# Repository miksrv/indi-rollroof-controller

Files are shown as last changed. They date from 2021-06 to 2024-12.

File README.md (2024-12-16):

# Observatory Roof Controller

 


A fork of the original [INDI Aldiroof](https://github.com/dokeeffe/indi-aldiroof) project by Derek O'Keeffe, designed for simplified roll-off roof mechanisms requiring only two signals: **OPEN** and **CLOSE**.

This project includes an [INDI](http://indilib.org/) driver and Arduino firmware to manage a roll-off roof for astronomical observatories.

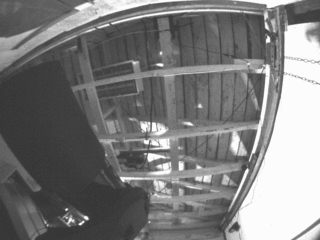
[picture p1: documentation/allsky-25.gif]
Observatory in Action


## Key Features

- **Efficient Roof Operation**: Control a motor-driven sliding gate reducer with just two signals.
- **Hardware Safety**: Includes limit switches for roof position and reed switches for telescope parking.
- **Simple Electronics**: Two 30A relays connected to an Arduino handle all roof movements.
- **Seamless Communication**: Uses the Firmata protocol for interaction between the Arduino and the INDI driver.

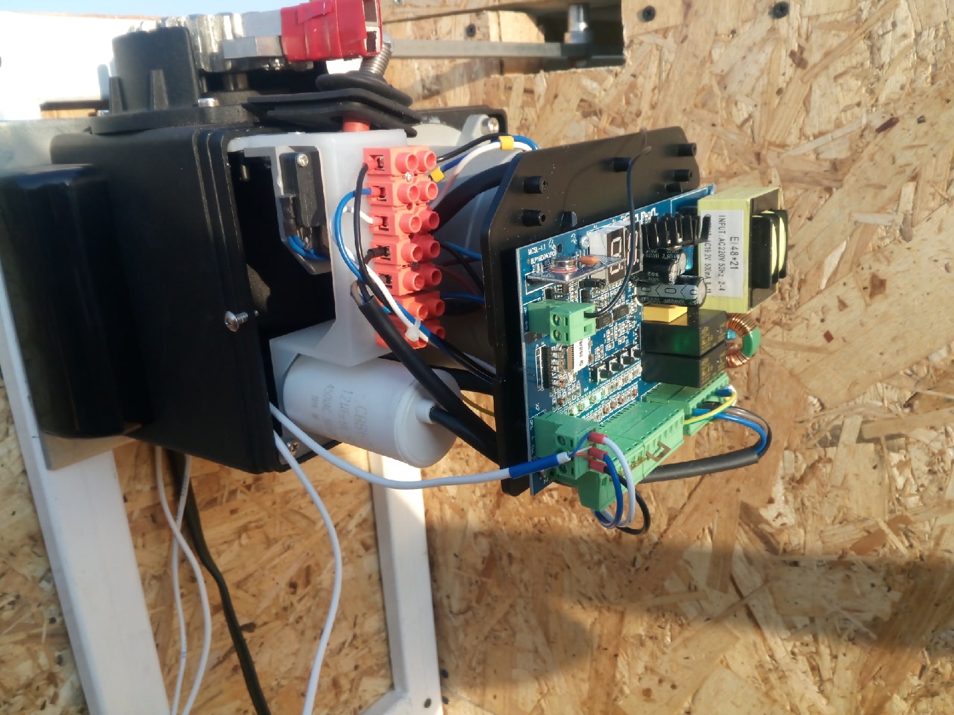
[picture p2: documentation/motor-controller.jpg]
Motor Controller Hardware


## Hardware Requirements

### Components
- **Microcontroller**: Arduino UNO (or compatible board).
- **Relays**: Two 30A relay modules.
- **Sensors**: Limit switches and reed switches for positional feedback.
- **Server**: A Linux-based machine running the INDI server.
- *(Optional)* A custom 3D-printed case for the hardware.

## Software Setup

### 1. Flashing the Arduino Firmware
1. Open the [Arduino IDE](https://www.arduino.cc/en/software).
2. Connect your Arduino board to your computer.
3. Navigate to the `arduino-firmware/RoofController` directory.
4. Open `RoofController.ino` and upload the firmware.

### 2. Building and Installing the INDI Driver

1. **Install Required Dependencies**  
   Make sure your system is up to date and install the necessary libraries:
   ```bash
   sudo apt-get update
   sudo apt-get install -y cmake libindi-dev libnova-dev
   ```

2. **Clone the Repository**  
   Clone this project to your machine:
   ```bash
   git clone <repository-url>
   cd <repository-directory>
   ```

3. **Build and Install the Driver**  
   Run the provided script:
   ```bash
   chmod +x ./indi-rollroof/install.sh
   ./indi-rollroof/install.sh
   ```
   This script will:
   - Create a `build` directory.
   - Configure the driver using `cmake`.
   - Compile and install the driver via `make install`.

### 3. Configuring the INDI Web Manager
To integrate the driver with the INDI Web Manager:
1. Open `/usr/share/indi/drivers.xml` for editing:
   ```bash
   sudo nano /usr/share/indi/drivers.xml
   ```
2. Add this configuration under the `<Domes>` section:
   ```xml
   <device label="Roll Roof" manufacturer="miksoft">
     <driver name="Roll Roof">indi_rollroof</driver>
     <version>1.0</version>
   </device>
   ```
3. Save and restart the INDI Web Manager.

### 4. Wiring and Hardware Setup
- Wire the Arduino with relays, sensors, and motor as outlined in the [wiring diagram](./documentation/arduino-controller.jpg).
- Ensure that:
  - Limit switches are positioned to detect the fully open and closed states.
  - Reed switches confirm the telescope’s parked position before closing the roof.

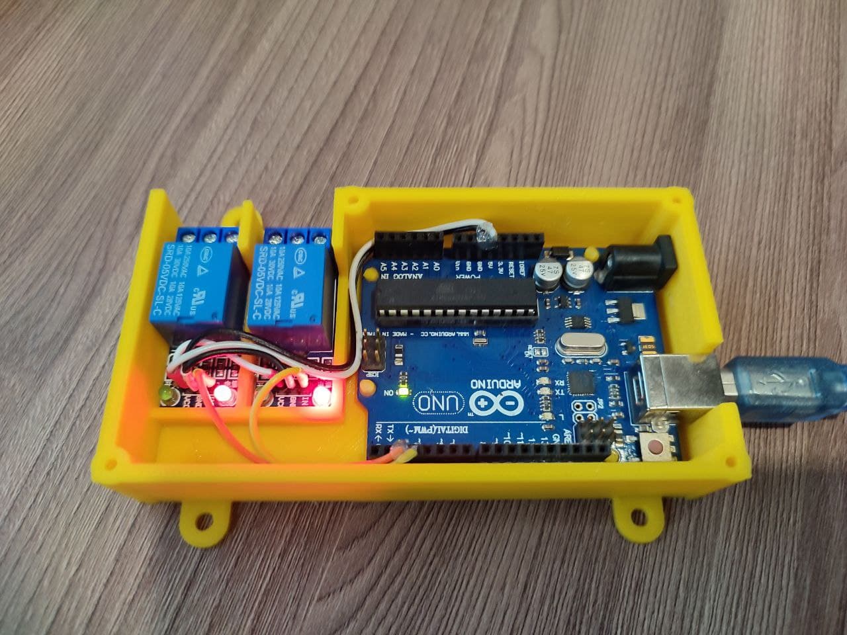
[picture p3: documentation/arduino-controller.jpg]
Arduino Wiring Diagram


## Contributing

Contributions are welcome! If you encounter bugs or have suggestions for improvements:
1. Fork the repository.
2. Create a feature branch.
3. Submit a pull request.

## Acknowledgments

This project is based on the work of [Derek O'Keeffe](https://github.com/dokeeffe/indi-aldiroof) and leverages the powerful [INDI Library](http://indilib.org/).  
Special thanks to the open-source community for enabling projects like this.

### License
This project is licensed under the [MIT License](./LICENSE).

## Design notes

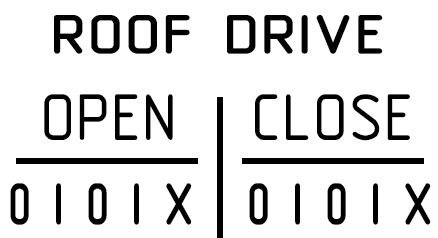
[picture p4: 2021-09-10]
models/label-1.png

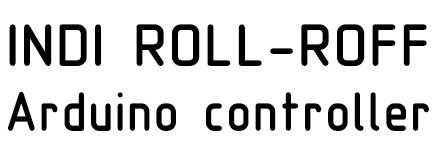
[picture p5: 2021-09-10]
models/label-3.png

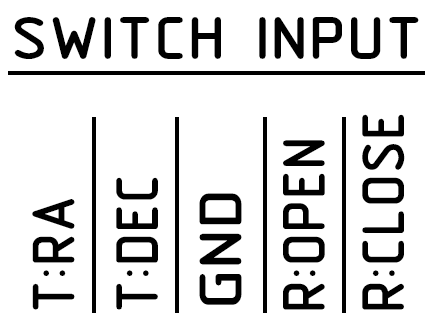
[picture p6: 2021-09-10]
models/label-2.png

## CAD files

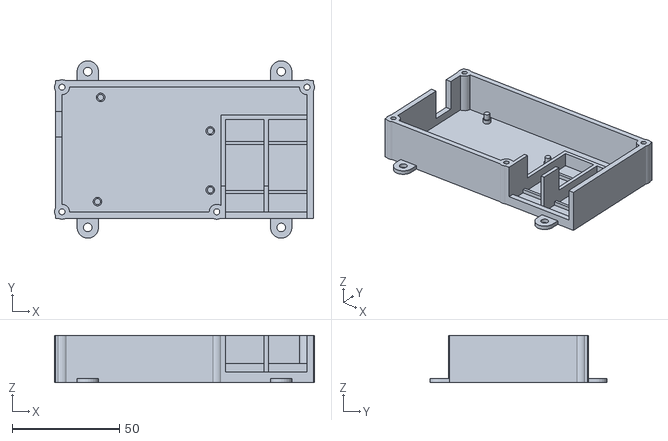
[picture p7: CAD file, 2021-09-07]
models/arduino-2relay-case.stl
121.0 x 82.5 x 22.0

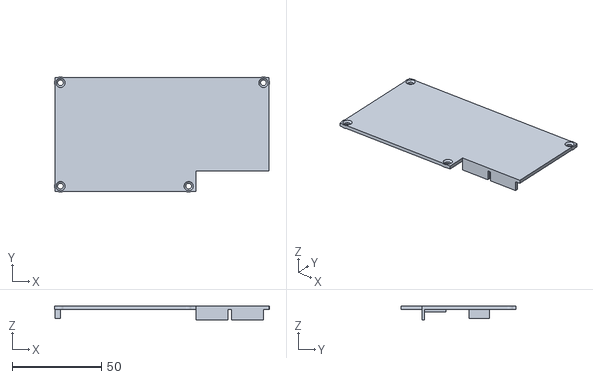
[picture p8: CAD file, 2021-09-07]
models/arduino-2relay-cover.stl
120.8 x 64.7 x 7.80

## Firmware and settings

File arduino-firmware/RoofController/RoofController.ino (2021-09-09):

/*******************************************************************************
 * OBSERVATORY ROLL-OFF-ROOF FIRMWARE
 * 
 * Firmware for a Arduino controller Roll-Off-Roof observatory. A simple 
 * state-machine based on StandardFirmata, comminicates with indiserver indi_rollroof driver.
 * NOTE: Firmata does not function well over USB3. Always use a USB2 port!
 * 
 * Sept 2015 Derek OKeeffe
 * Sept 2019 Mikhail Topchilo (miksoft.pro)
*******************************************************************************/
#include <Wire.h>
#include <Firmata.h>

/**
 * ======= CONFIGURATION =======
 */
// If the variable is not commented out, debug mode is activated, messages are sent to the serial port
// #define DEBUG

const int pinRelayOpen        = 2; // RELAY: Open roof
const int pinRelayClose       = 3; // RELAY: Close roof
const int pinLimitSwitchClose = 4; // SWITCH: Closed roof limit switch 
const int pinLimitSwitchOpen  = 5; // SWITCH: Opened roof limit switch 
const int parkTelescopeDEC    = 6; // SWITCH: Telescope parking position on the axis DEC
const int parkTelescopeRA     = 7; // SWITCH: Telescope parking position on the axis RA
const int ledPin              = 13; // INDICATOR: Pin for connecting a visual indicator of the roof position (for DEBUG)

long ledToggleTime = 0;
bool ledState;
int openState, closeState, parkStateRa, parkStateDec;

/**
 * ======= SETUP =======
 */
void setup()
{
  Firmata.setFirmwareVersion(FIRMATA_MAJOR_VERSION, FIRMATA_MINOR_VERSION);
  Firmata.attach(STRING_DATA, stringCallback);
  Firmata.begin(57600);
  pinMode(pinRelayOpen, OUTPUT);
  pinMode(pinRelayClose, OUTPUT);
  
  pinMode(pinLimitSwitchOpen, INPUT_PULLUP); // INPUT
  pinMode(pinLimitSwitchClose, INPUT_PULLUP); // INPUT

  pinMode(parkTelescopeRA, INPUT_PULLUP);
  pinMode(parkTelescopeDEC, INPUT_PULLUP);
  
  pinMode(ledPin, OUTPUT);

  // By default, the relays should be turned off, so we give them a high signal 
  digitalWrite(pinRelayOpen, HIGH);
  digitalWrite(pinRelayClose, HIGH);
}

/**
 * ======= LOOP =======
 */
void loop()
{
  while (Firmata.available()) {
    Firmata.processInput();
  }

  #ifdef DEBUG
    debugLEDs();
  #endif
}

/**
 * ======= FIRMATA HANDLER =======
 */
void stringCallback(char *myString) {
  openState  = digitalRead(pinLimitSwitchOpen);
  closeState = digitalRead(pinLimitSwitchClose);
  parkStateRa  = digitalRead(parkTelescopeRA);
  parkStateDec = digitalRead(parkTelescopeDEC);
  
  String commandString = String(myString);

  // CMD: Open roof
  if (commandString.equals("OPEN") && (parkStateRa == LOW && parkStateDec == LOW))
    actionRoofOpen();

  // CMD: Close roof
  else if (commandString.equals("CLOSE") && (parkStateRa == LOW && parkStateDec == LOW))
    actionRoofClose();

  // CMD: Abort command
  else if (commandString.equals("ABORT")) {
    return ;
  }

  // CMD: Query status
  /**
   * 10 - Roof closed, telescope parked
   * 20 - Roof open, telescope parked
   *
   * 11 - Roof closed, no parking (DEC, RA)
   * 12 - Roof closed, no parking (DEC)
   * 13 - Roof closed, no parking (RA)
   *
   * 21 - Roof open, no parking (DEC, RA)
   * 22 - Roof open, no parking (DEC)
   * 23 - Roof open, no parking (RA)
   */
  else if (commandString.equals("QUERY")) {
    int stateRoof;
    int statePark;

    if (openState == LOW && closeState == HIGH)
      stateRoof = 10; // Open roof
    
    else if (openState == HIGH && closeState == LOW)
      stateRoof = 20; // Close roof

    else
      stateRoof = 30; // Unknow


    if (parkStateDec == LOW && parkStateRa == LOW)
      statePark = 0; // PARK
      
    else if (parkStateDec == HIGH && parkStateRa == HIGH)
      statePark = 1; // NO park DEC, RA 

    else if (parkStateDec == HIGH && parkStateRa == LOW)
      statePark = 2; // NO park DEC

    else if (parkStateDec == LOW && parkStateRa == HIGH)
      statePark = 3; // NO park RA

      char cstr[8];

    return Firmata.sendString( itoa(stateRoof + statePark, cstr, 10) );
  }
}

/**
 * Close roof
 */
void actionRoofClose() {
  unsigned long activateTime = millis();

  digitalWrite(pinRelayOpen, LOW);
  while((millis() - activateTime) < 800) {}
  digitalWrite(pinRelayOpen, HIGH);
}

/**
 * Open roof
 */
void actionRoofOpen() {
  unsigned long activateTime = millis();
  
  digitalWrite(pinRelayClose, LOW);
  while((millis() - activateTime) < 800) {}
  digitalWrite(pinRelayClose, HIGH);
}

/** 
 * LED is used to provide visual clues to the state of the roof controller.
 * Really not necessary, but handy for debugging wiring and mechanical problem.
 */
void debugLEDs() {
  openState  = digitalRead(pinLimitSwitchOpen);
  closeState = digitalRead(pinLimitSwitchClose);
  
  // Opened roof
  if (closeState == HIGH && openState == LOW)
    toggleLed(200);

  // Closed roof
  else if (closeState == LOW && openState == HIGH)
    toggleLed(1000);

  // Where is roof, wtf?
  else
    digitalWrite(ledPin, LOW);
}

void toggleLed(int duration) {
  if (millis() - ledToggleTime > duration) {
    ledToggleTime = millis();
    
    if (ledState == false ) {
      ledState = true;
      digitalWrite(ledPin, HIGH);
    } else {
      ledState = false;
      digitalWrite(ledPin, LOW);
    }
  }
}

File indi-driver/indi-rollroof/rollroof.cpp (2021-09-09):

/*******************************************************************************
 * OBSERVATORY ROLL-OFF-ROOF DRIVER
 * Controls an arduino using firmata to switch on/off relays.
 * NOTE: Firmata does not function well over USB3. Always use a USB2 port!
 * 
 * Sept 2015 Derek OKeeffe
 * Sept 2019 Mikhail Topchilo (miksoft.pro)
*******************************************************************************/
#include "rollroof.h"

#include <stdio.h>
#include <stdlib.h>
#include <unistd.h>
#include <math.h>
#include <string.h>

#include <memory>

#include <indicom.h>
#include "connectionplugins/connectionserial.h"

std::unique_ptr<RollRoof> rollOff(new RollRoof());

// This is the max ontime (sec) for the motors. Safety cut out.
#define MAX_ROLLOFF_DURATION 19 

void ISPoll(void *p);

void ISInit()
{
   static int isInit =0;

   if (isInit == 1)
       return;

    isInit = 1;

    if (rollOff.get() == 0)
        rollOff.reset(new RollRoof());

}

void ISGetProperties(const char *dev)
{
    ISInit();
    rollOff->ISGetProperties(dev);
}

void ISNewSwitch(const char *dev, const char *name, ISState *states, char *names[], int num)
{
    ISInit();
    rollOff->ISNewSwitch(dev, name, states, names, num);
}

void ISNewText(	const char *dev, const char *name, char *texts[], char *names[], int num)
{
    ISInit();
    rollOff->ISNewText(dev, name, texts, names, num);
}

void ISNewNumber(const char *dev, const char *name, double values[], char *names[], int num)
{
    ISInit();
    rollOff->ISNewNumber(dev, name, values, names, num);
}

void ISNewBLOB (const char *dev, const char *name, int sizes[], int blobsizes[], char *blobs[], char *formats[], char *names[], int n)
{
    INDI_UNUSED(dev);
    INDI_UNUSED(name);
    INDI_UNUSED(sizes);
    INDI_UNUSED(blobsizes);
    INDI_UNUSED(blobs);
    INDI_UNUSED(formats);
    INDI_UNUSED(names);
    INDI_UNUSED(n);
}

void ISSnoopDevice (XMLEle *root)
{
    ISInit();
    rollOff->ISSnoopDevice(root);
}

RollRoof::RollRoof()
{
  fullOpenLimitSwitch   = ISS_OFF;
  fullClosedLimitSwitch = ISS_OFF;
  bTelescopeParkingDEC  = false;
  bTelescopeParkingRA   = false;

  MotionRequest = 0;

  SetDomeCapability(DOME_CAN_ABORT | DOME_CAN_PARK);
}

/**
 * Init all properties
 */
bool RollRoof::initProperties()
{
    DEBUG(INDI::Logger::DBG_SESSION, "Init props");

    INDI::Dome::initProperties();

    SetParkDataType(PARK_NONE);
    addAuxControls();

    IUFillText(&CurrentStateT[0], "ROOF", "Position status", NULL);
    IUFillTextVector(&CurrentStateTP, CurrentStateT, 1, getDeviceName(), "ROOF", "Roll-off-roof", MAIN_CONTROL_TAB, IP_RO, 60, IPS_IDLE);

    IUFillText(&CurrentParkT[0], "TELESCOPE", "Park status", NULL);
    IUFillTextVector(&CurrentParkTP, CurrentParkT, 1, getDeviceName(), "TELESCOPE", "Telescope", MAIN_CONTROL_TAB,IP_RO, 60, IPS_IDLE);

    return true;
}

bool RollRoof::ISSnoopDevice (XMLEle *root)
{
	return INDI::Dome::ISSnoopDevice(root);
}

bool RollRoof::Connect()
{
    sf = new Firmata(serialConnection->port());
    if (sf->portOpen) {
        sf->OnIdle();

		if (strstr(sf->firmata_name, "RoofController")) {
			DEBUG(INDI::Logger::DBG_SESSION, "ARDUINO BOARD CONNECTED");
			DEBUGF(INDI::Logger::DBG_SESSION, "FIRMATA VERSION: %s",sf->firmata_name);
			return true;
		} else {
		    DEBUG(INDI::Logger::DBG_SESSION, "ARDUINO BOARD INCOMPATABLE FIRMWARE");
		    DEBUGF(INDI::Logger::DBG_SESSION, "FIRMATA VERSION: %s",sf->firmata_name);
		    return false;
		}

    } else {
        DEBUG(INDI::Logger::DBG_SESSION, "ARDUINO BOARD FAIL TO CONNECT");
        delete sf;
        return false;
    }
}

RollRoof::~RollRoof()
{

}

const char * RollRoof::getDefaultName()
{
    return (char *)"Roll Roof";
}

bool RollRoof::ISNewSwitch (const char *dev, const char *name, ISState *states, char *names[], int n)
{
	return INDI::Dome::ISNewSwitch(dev, name, states, names, n);
}

/**
 * Update properties from Arduino controller
 */
bool RollRoof::updateProperties()
{
    DEBUG(INDI::Logger::DBG_SESSION, "Updating controller props ...");
    INDI::Dome::updateProperties();

    if (isConnected())
    {
        fullOpenLimitSwitch   = ISS_OFF;
        fullClosedLimitSwitch = ISS_OFF;
        bTelescopeParkingDEC  = false;
        bTelescopeParkingRA   = false;

        getControllerState();

        defineText(&CurrentStateTP);
        defineText(&CurrentParkTP);
    } 

    else {
	   deleteProperty(CurrentStateTP.name);
       deleteProperty(CurrentParkTP.name);
    }

    return true;
}

/**
* Disconnect from the Arduino
*/
bool RollRoof::Disconnect()
{
    sf->closePort();
    delete sf;

    MotionRequest =- 1;

    DEBUG(INDI::Logger::DBG_SESSION, "ARDUINO BOARD DISCONNECTED");
    IDSetSwitch (getSwitch("CONNECTION"),"DISCONNECTED\n");

    return true;
}

/**
 * TimerHit gets called by the indi client every 1 sec when the roof is moving.
 */
void RollRoof::TimerHit()
{

    DEBUG(INDI::Logger::DBG_DEBUG, "Timer hit");
    
    if (isConnected() == false) return;  //  No need to reset timer if we are not connected anymore
    if (DomeMotionSP.s != IPS_BUSY) return;

    // (ABORT) The safety timer has expired called MAX_ROLLOFF_DURATION
    if (MotionRequest < 0) {
        DEBUG(INDI::Logger::DBG_WARNING, "Roof motion is stopped, the safety timer has expired");
        setDomeState(DOME_IDLE);

        string stateString = "ABORTED";
        char roofStatus[32];
        strcpy(roofStatus, stateString.c_str());

        IUSaveText(&CurrentStateT[0], roofStatus);
        IDSetText(&CurrentStateTP, NULL);

        SetTimer(500);

        return;
    }

    // Roll off is OPENING
    if (DomeMotionS[DOME_CW].s == ISS_ON) {
        string stateString = "MOVE: OPENING...";

        if (getFullOpenedLimitSwitch()) {
            setDomeState(DOME_UNPARKED);
            SetParked(false);
            IUResetSwitch(&ParkSP);

            ParkS[1].s = ISS_ON;
            ParkSP.s = IPS_OK;

            updateProperties();

            return;
        }

        char status[32];

        strcpy(status, stateString.c_str());

        IUSaveText(&CurrentStateT[0], status);
        IDSetText(&CurrentStateTP, NULL);

        if (CalcTimeLeft(MotionStart) <= 0) {
            DEBUG(INDI::Logger::DBG_WARNING, "Exceeded max motor run duration. Aborting.");
            Abort();
        }
    }

    // Roll Off is CLOSING
    else if (DomeMotionS[DOME_CCW].s == ISS_ON) {
        string stateString = "MOVE: CLOSING...";

        if (getFullClosedLimitSwitch()) {
            setDomeState(DOME_PARKED);
            SetParked(true);

            updateProperties();

            return;
        }

        char status[32];

        strcpy(status, stateString.c_str());

        IUSaveText(&CurrentStateT[0], status);
        IDSetText(&CurrentStateTP, NULL);

        if (CalcTimeLeft(MotionStart) <= 0) {
            DEBUG(INDI::Logger::DBG_WARNING, "Exceeded max motor run duration. Aborting.");
            Abort();
        }
    }

    SetTimer(500);
}
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

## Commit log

2021-09-07 feat: Add gitignore, photos. Read documentation, delete build folder, edit Arduino firmware
    [arduino-2relay-case.stl, arduino-2relay-cover.stl]
2021-09-08 feat: Refracrtor arduino controller firmware and add telescope status code
2021-09-09 feat: Reafract Arduino firmware and INDI driver (more changes)
2021-09-10 docs: Add image labels for controller 3D case
2026-10-30 Port the driver to INDI 2.x
    The driver no longer built after the move to INDI 2: the global IS*
    entry points, DEBUG macros and the old property structs are gone.
    Build:
    - CMake 3.18+, C++17, link libindidriver directly; drop the bundled
    FindINDI/FindNova modules (libnova is not used)
    - default install prefix /usr, where INDI looks for drivers and XML
    - driver version 2.0
    Driver:
    - INDI 2 API: LOG_* macros, PropertySwitch accessors, defineProperty;
    INDI dispatches ISNew*/ISGetProperties to the device itself
    - QUERY waits up to 1 s for a fresh answer instead of reusing a stale
    buffer; limit switch and reed flags are reset on every query
    - no updateProperties() on every move/limit hit,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
2026-10-30 Block roof motion unless the mount is parked in software
    At park the telescope tube lies just under the roof, so a roof moving
    over an unparked mount wrecks the equipment. Until now the only guard
    was the pair of park reed switches.
    The driver now snoops TELESCOPE_PARK of the ACTIVE_TELESCOPE and moves
    the roof (both directions, via DOME_PARK or DOME_MOTION) only when the
    mount driver reports a settled PARK (state Ok) AND both reed switches
    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
2026-10-30 Build INDI 2 in CI and harden build.sh
    - CI installs libindi-dev from the INDI PPA (ppa:mutlaqja/ppa), so the
    driver is built against the current INDI 2.x release instead of
    whatever the runner's Ubuntu ships; libnova-dev stays because the
    INDI headers include libnova headers
    - CI checks that the binary and its XML were installed
    - build.sh stops on the first error, works from any directory, builds
    in parallel and starts from a clean build directory
    - arduino-check uses actions/checkout@v4
2026-10-30 Document INDI 2 setup, the safety interlock and the hardware
    README:
    - INDI 2.x build from the INDI PPA, correct build.sh path, what gets
    installed; drop the manual drivers.xml edit (the driver installs its
    own XML into /usr/share/indi)
    - driver configuration: by-id port, ACTIVE_TELESCOPE, Mount/Dome locks
    - new "Safety Interlock" section: when the roof is allowed to move,
    what counts as not parked, shutdown order (mount first, roof second)
    documentation/hardware.md (new): pinout and signal levels, the swapped
    relay names in the sketch, gate-motor behaviour (no mid-travel stop,
    ABORT is a no-op), the Firmata command set and QUERY codes, and
    troubleshooting for the limit and reed switc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
2026-10-30 Add CHANGELOG, CLAUDE.md, MIT license; fix and modernize CI
    - CHANGELOG.md starting at 2.0.0 (the INDI 2 port), format: version
    heading, one-line summary, Patch/Minor/Major Changes bullets
    - CLAUDE.md: layout, build and CI commands, the roof safety rules,
    code conventions, versioning, CHANGELOG format and the release flow
    - LICENSE: MIT, which the README already referred to
    CI: the driver build failed because the INDI PPA publishes INDI 2.x
    only for Ubuntu 26.04 (amd64), so apt on the 24.04 runner fell back to
    the distribution's INDI 1.9 headers. The ubuntu-26.04 runner does not
    help either: its apt prefers amd64v3 archive packages (INDI 1.9 again).
    - driver-build.yml (was cmake-multi-p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
2026-10-30 Release 2.0.1: list the driver in INDI Web Manager, report its version
    - The driver XML had no <driversList> root, so the INDI Web Manager and
    KStars skipped it and Roll Roof was missing from their driver lists
    (hence the old manual drivers.xml edit). It now has the root, an XML
    declaration and a manufacturer, like the stock INDI driver files.
    - The XML is generated from indi_rollroof.xml.cmake, and the driver gets
    major/minor as compile definitions for setVersion(), so the version
    lives only in CMakeLists.txt (now with VERSION_PATCH). DRIVER_INFO
    reported 1.0 because setVersion() was never called.
    - CI checks the installed XML has the <driversList> root.
    - CHANGELOG 2.0.1; CLAUD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
2026-11-02 CI: run both builds on every pull request so they can be required checks
    The driver and firmware workflows only ran when their own directories
    changed. A pull request that touches neither (docs, CI, Dependabot) would
    leave a required check waiting forever, so the path filters are dropped;
    both builds take a few minutes.
2026-11-02 README: add release and license badges, restructure for the GitHub front page
    Badges for the latest release and the license next to the two build
    badges, a one-paragraph pitch, a 'How it works' overview, a hardware
    table, project structure and a development section with the release flow.
    The driver configuration and safety interlock sections are kept as they
    were.
2026-11-02 CI: one Checks workflow with a required 'Checks passed' gate and path-gated builds
    The driver and firmware builds move into .github/workflows/checks.yml.
    A 'changes' job (dorny/paths-filter) runs them only when indi-driver/ or
    arduino-firmware/ changed; a manual run builds everything. The final
    'Checks passed' job always runs, fails if a build failed or was cancelled,
    and is the only status check main requires, so a documentation-only pull
    request is mergeable without building anything. README and CLAUDE.md
    describe the new layout; the README now has one Checks badge.
2026-11-03 Driver: check the roof and park switches while idle (2.1.0)
    The driver queried the Arduino only on connect, before its own moves and
    while watching them, so a roof opened by other means (the gate controller's
    remote, a power relay) kept showing CLOSED / parked, and a WatchDog or
    Scheduler shutdown saw "Dome already parked" and left it open.
    - While idle, QUERY the controller every Status poll seconds (new
    Options -> Status poll, 2-60 s, default 5, saved in the config).
    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
2026-11-03 Review fixes: unknown roof, standard polling period, quieter errors
    - A roof with neither limit switch closed (stopped part-way, still
    travelling after an abort) is DOME_UNKNOWN instead of keeping the last
    park state: a WatchDog/Scheduler shutdown closes it, and a mount with
    Dome locks stays locked (it only follows a settled DOME_PARK).
    - The idle check uses the standard Options -> Polling period (default
    5000 ms, at least 1000) instead of a second, separate setting; every
    30 s while the controller does not answer, since each unanswered query
    blocks the driver for about a second.
    - A malformed answer is handled like a missing one: UNKNOWN published and
    logged once.
    - The end of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
